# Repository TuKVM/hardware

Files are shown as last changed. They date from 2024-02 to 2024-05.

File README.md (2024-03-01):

# TuKVM Hardware

TuKVM is a hardware project that aims to provide a simple but feature rich IP KVM solution. The project is based on the [Tronlong SOM-TLT113](https://www.tronlong.com/Product/show/237.html) SoM, which includes an Allwinner T113-i SoC, with dual-core Cortex-A7 CPU, 256MB DDR3 RAM, and 4GB eMMC.

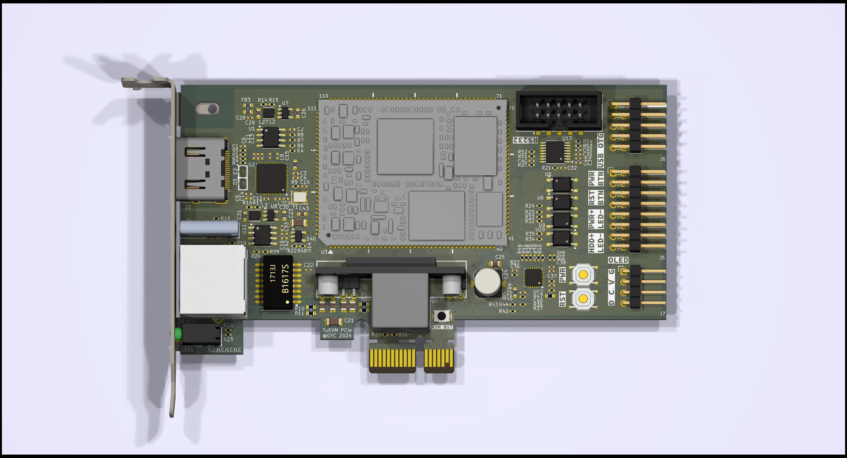
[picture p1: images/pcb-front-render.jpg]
PCB render image


## Features

* PCIe x1 half-height form factor, with breakable edge connector for mounting in systems without free slots
* HDMI input capture (up to 1080P30) with [MS2109](http://en.macrosilicon.com/info.asp?base_id=2&third_id=50) IC
* ATX power / reset button control with opto-isolator
* Power and HDD LED monitoring with opto-isolator
* 9 pin 2.54mm internal USB OTG port for mass-storage, keyboard, mouse emulation and Ethernet-over-USB
* USB-C external power input and UART console port for debugging
* 100Mbps Ethernet with [LAN8720A](https://www.microchip.com/en-us/product/lan8720a) PHY
* RS232 serial port with 2.54mm header for host system console redirection
* SMBus on PCIe connector for Linux kernel to recongnize the KVM as an IPMI device, using [ipmi_ssif](https://github.com/torvalds/linux/blob/master/drivers/char/ipmi/ipmi_ssif.c) driver
* (Optional) Isolated 802.3af PoE input with [DP1435-5V](https://item.szlcsc.com/6245786.html) controller module
* (Optional) I2C connector for an OLED status display module.

## Status

This project is currently in the prototyping phase. The hardware design is mostly complete, and the first prototype PCBs have been ordered. 

The firmware and software development isn't started yet, but the plan is to port [kvmd](https://github.com/pikvm/kvmd) from PiKVM project to the Allwinner T113-i SoC. Support for SMBus and IPMI protocol will need extra driver and software development. Any help is welcome!

## License

This project is licensed under the CERN Open Hardware License v2 - Permissive license. See the [LICENSE](LICENSE) file for details.

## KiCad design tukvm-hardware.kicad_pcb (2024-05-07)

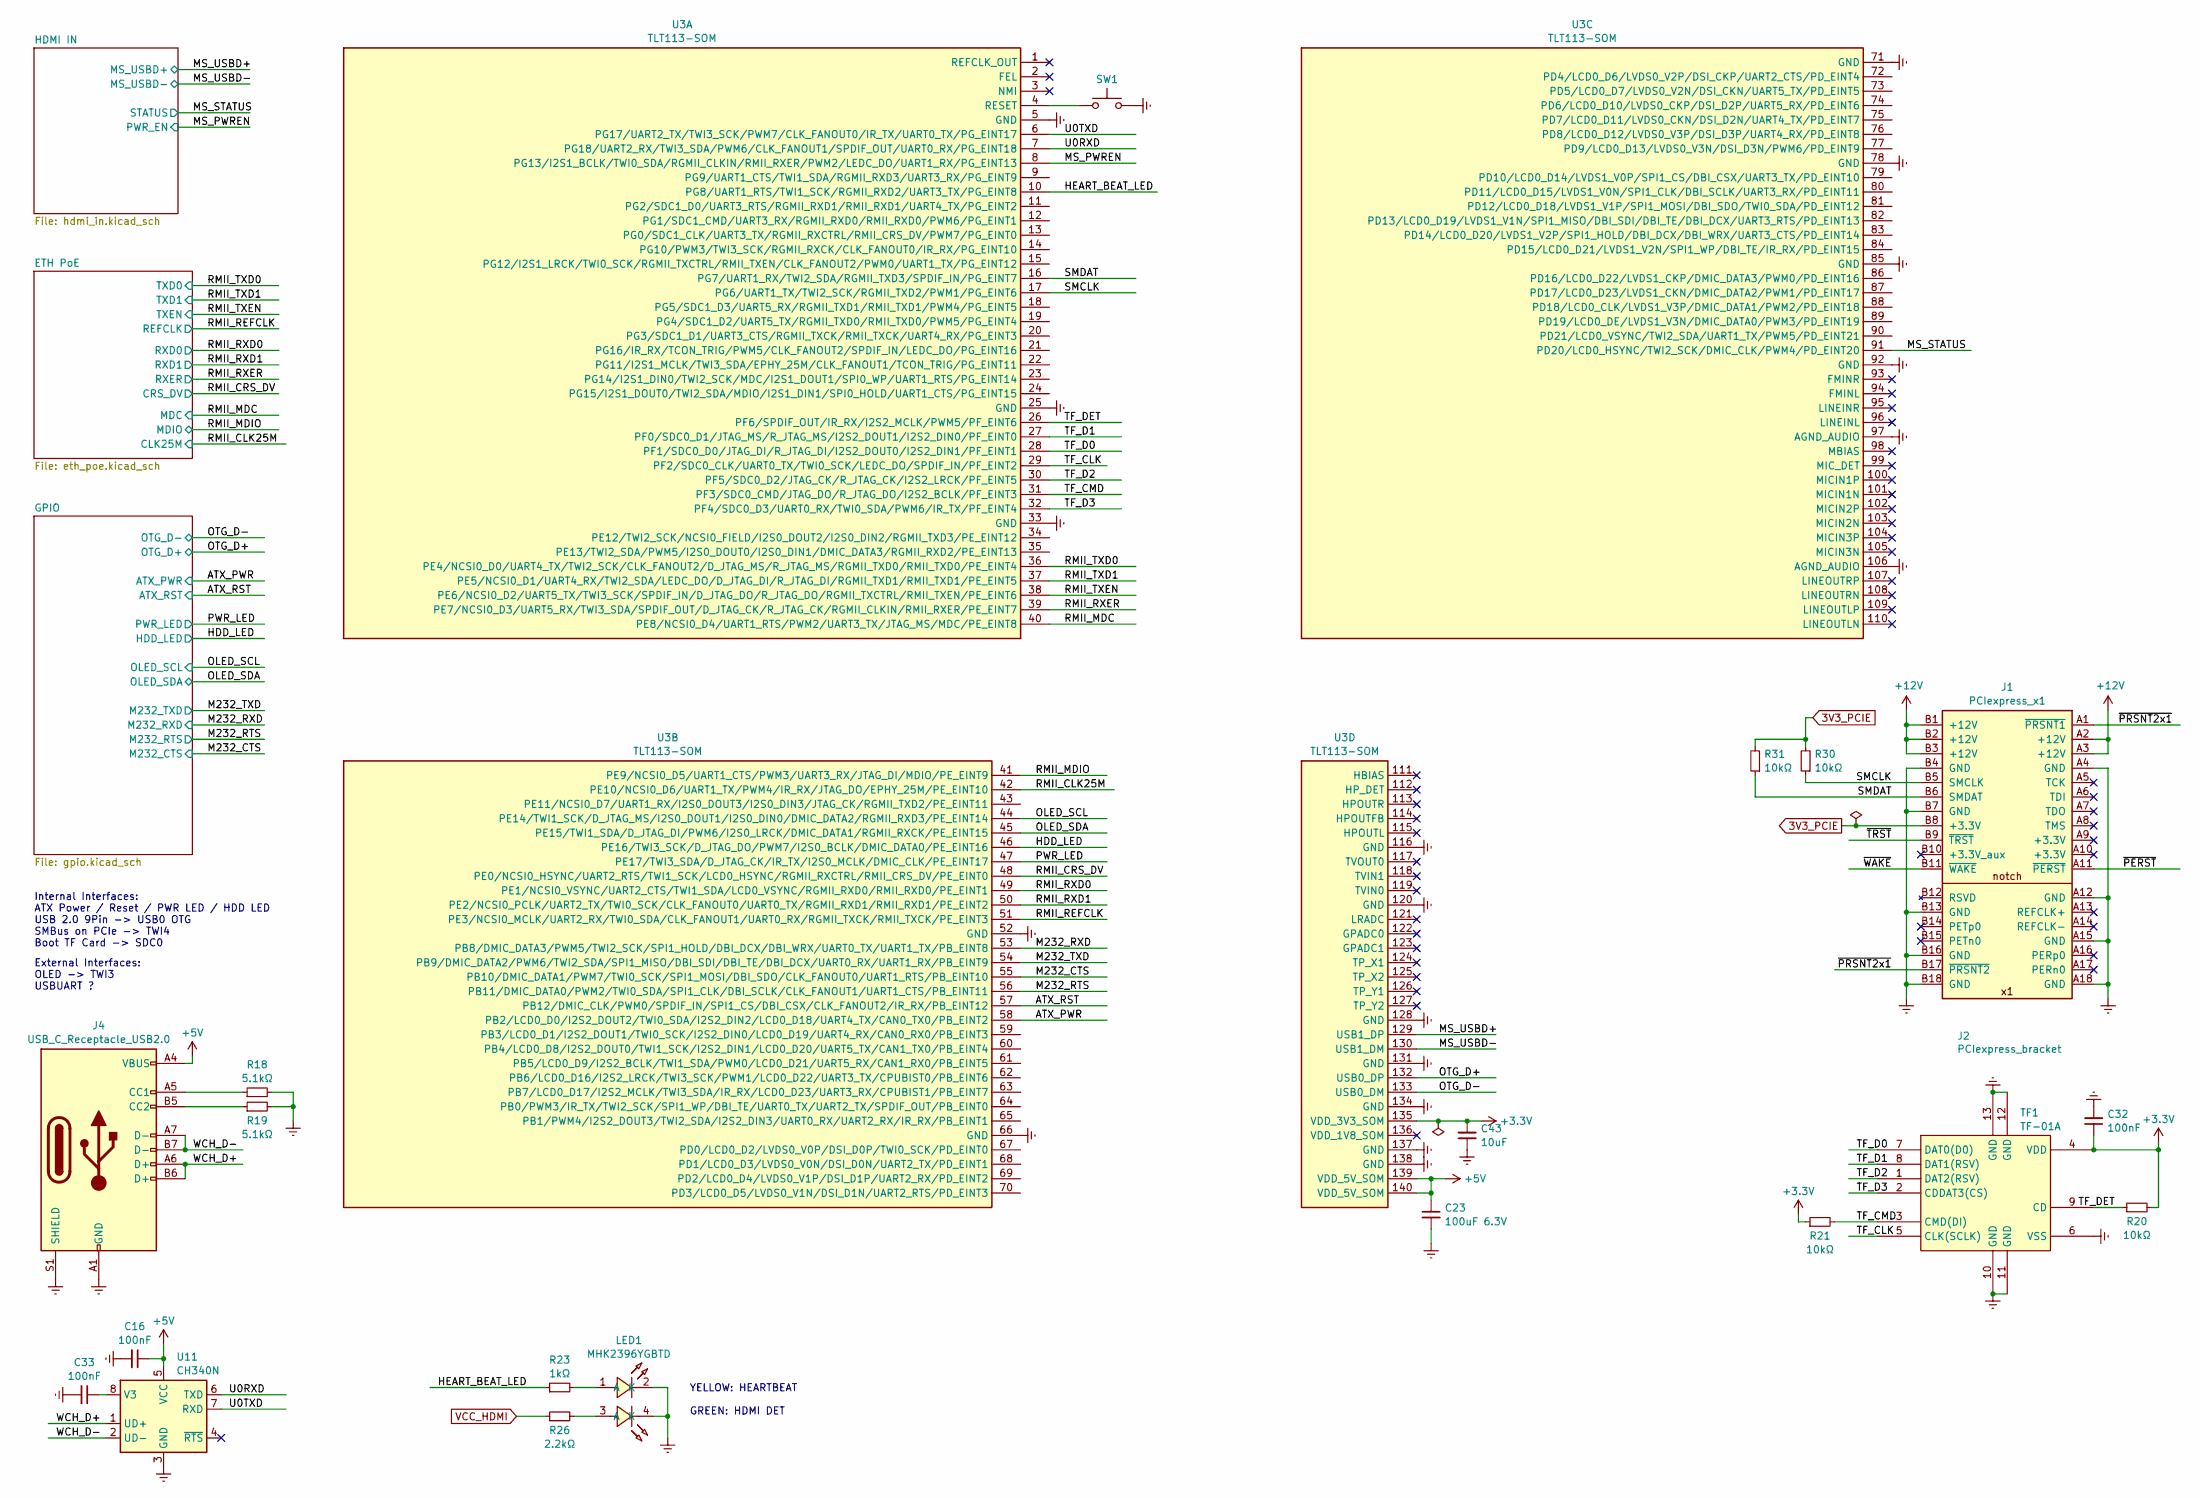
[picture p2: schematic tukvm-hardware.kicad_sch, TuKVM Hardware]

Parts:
C16, C32, C33: 100nF; C_0402_1005Metric
C23: 100uF 6.3V; C_1206_3216Metric
C43: 10uF; C_0603_1608Metric
J1: PCIexpress_x1
J2: PCIexpress_bracket; PCIexpress_bracket_low
J4: USB_C_Receptacle_USB2.0; USB-C-TH_TYPE-C-31-M-18
LED1: MHK2396YGBTD; LED-TH_MHK2396YGBTD; LCSC Part C2764899
R18, R19: 5.1kΩ; R_0402_1005Metric
R20, R21, R30, R31: 10kΩ; R_0402_1005Metric
R23: 1kΩ; R_0402_1005Metric
R26: 2.2kΩ; R_0402_1005Metric
SW1: SKRK; SW_Push_SPST_NO_Alps_SKRK
TF1: TF-01A; TF-SMD_TF-01A; LCSC Part C91145
U3: TLT113-SOM; SMD_140P_35X45_SOM_TLT113_PackageLength
U11: CH340N; SOP-8_3.9x4.9mm_P1.27mm

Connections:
3V3_PCIE: J1.B8 (+3.3V), R30.2, R31.2
+3.3V: C32.1, C43.2, R20.2, R21.1, TF1.4 (VDD), U3.135 (VDD_3V3_SOM); also elsewhere on the board
+5V: C16.1, C23.1, J4.A4 (VBUS), J4.A9 (VBUS), J4.B4 (VBUS), J4.B9 (VBUS), U3.139 (VDD_5V_SOM), U3.140 (VDD_5V_SOM), U11.5 (VCC); also elsewhere on the board
+12V: J1.A2 (+12V), J1.A3 (+12V), J1.B1 (+12V), J1.B2 (+12V), J1.B3 (+12V)
/ATX_PWR: U3.58 (PB2/LCD0_D0/I2S2_DOUT2/TWI0_SDA/I2S2_DI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); also elsewhere on the board
/ATX_RST: U3.57 (PB12/DMIC_CLK/PWM0/SPDIF_IN/SPI1_CS/DBI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); also elsewhere on the board
/HDD_LED: U3.46 (PE16/TWI3_SCK/D_JTAG_DO/PWM7/I2S0_BCLK/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); also elsewhere on the board
/HEART_BEAT_LED: R23.1, U3.10 (PG8/UART1_RTS/TWI1_SCK/RGMII_RXD2/UART3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)
/M232_CTS: U3.55 (PB10/DMIC_DATA1/PWM7/TWI0_SCK/SPI1_MOSI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); also elsewhere on the board
/M232_RTS: U3.56 (PB11/DMIC_DATA0/PWM2/TWI0_SDA/SPI1_CLK/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); also elsewhere on the board
/M232_RXD: U3.53 (PB8/DMIC_DATA3/PWM5/TWI2_SCK/SPI1_HOLD/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); also elsewhere on the board
/M232_TXD: U3.54 (PB9/DMIC_DATA2/PWM6/TWI2_SDA/SPI1_MISO/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); also elsewhere on the board
/MS_PWREN: U3.8 (PG13/I2S1_BCLK/TWI0_SDA/RGMII_CLKIN/RMI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); also elsewhere on the board
/MS_STATUS: U3.91 (PD20/LCD0_HSYNC/TWI2_SCK/DMIC_CLK/PWM4/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); also elsewhere on the board
/MS_USBD+: U3.129 (USB1_DP); also elsewhere on the board
/MS_USBD-: U3.130 (USB1_DM); also elsewhere on the board
/OLED_SCL: U3.44 (PE14/TWI1_SCK/D_JTAG_MS/I2S0_DOUT1/I2S0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); also elsewhere on the board
/OLED_SDA: U3.45 (PE15/TWI1_SDA/D_JTAG_DI/PWM6/I2S0_LRCK/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); also elsewhere on the board
/OTG_D+: U3.132 (USB0_DP); also elsewhere on the board
/OTG_D-: U3.133 (USB0_DM); also elsewhere on the board
/PWR_LED: U3.47 (PE17/TWI3_SDA/D_JTAG_CK/IR_TX/I2S0_MCLK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); also elsewhere on the board
/RMII_CLK25M: U3.42 (PE10/NCSI0_D6/UART1_TX/PWM4/IR_RX/JTAG_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); also elsewhere on the board
/RMII_CRS_DV: U3.48 (PE0/NCSI0_HSYNC/UART2_RTS/TWI1_SCK/LCD0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); also elsewhere on the board
/RMII_MDC: U3.40 (PE8/NCSI0_D4/UART1_RTS/PWM2/UART3_TX/JT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); also elsewhere on the board
/RMII_MDIO: U3.41 (PE9/NCSI0_D5/UART1_CTS/PWM3/UART3_RX/JT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); also elsewhere on the board
/RMII_REFCLK: U3.51 (PE3/NCSI0_MCLK/UART2_RX/TWI0_SDA/CLK_FA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); also elsewhere on the board
/RMII_RXD0: U3.49 (PE1/NCSI0_VSYNC/UART2_CTS/TWI1_SDA/LCD0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); also elsewhere on the board
/RMII_RXD1: U3.50 (PE2/NCSI0_PCLK/UART2_TX/TWI0_SCK/CLK_FA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); also elsewhere on the board
/RMII_RXER: U3.39 (PE7/NCSI0_D3/UART5_RX/TWI3_SDA/SPDIF_OU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); also elsewhere on the board
/RMII_TXD0: U3.36 (PE4/NCSI0_D0/UART4_TX/TWI2_SCK/CLK_FANO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); also elsewhere on the board
/RMII_TXD1: U3.37 (PE5/NCSI0_D1/UART4_RX/TWI2_SDA/LEDC_DO/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); also elsewhere on the board
/RMII_TXEN: U3.38 (PE6/NCSI0_D2/UART5_TX/TWI3_SCK/SPDIF_IN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); also elsewhere on the board
/SMCLK: J1.B5 (SMCLK), R30.1, U3.17 (PG6/UART1_TX/TWI2_SCK/RGMII_TXD2/PWM1/P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)
/SMDAT: J1.B6 (SMDAT), R31.1, U3.16 (PG7/UART1_RX/TWI2_SDA/RGMII_TXD3/SPDIF_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)
/TF_CLK: TF1.5 (CLK(SCLK)), U3.29 (PF2/SDC0_CLK/UART0_TX/TWI0_SCK/LEDC_DO/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)
/TF_CMD: R21.2, TF1.3 (CMD(DI)), U3.31 (PF3/SDC0_CMD/JTAG_DO/R_JTAG_DO/I2S2_BCL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)
/TF_D0: TF1.7 (DAT0(D0)), U3.28 (PF1/SDC0_D0/JTAG_DI/R_JTAG_DI/I2S2_DOUT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)
/TF_D1: TF1.8 (DAT1(RSV)), U3.27 (PF0/SDC0_D1/JTAG_MS/R_JTAG_MS/I2S2_DOUT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)
/TF_D2: TF1.1 (DAT2(RSV)), U3.30 (PF5/SDC0_D2/JTAG_CK/R_JTAG_CK/I2S2_LRCK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)
/TF_D3: TF1.2 (CDDAT3(CS)), U3.32 (PF4/SDC0_D3/UART0_RX/TWI0_SDA/PWM6/IR_T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)
/TF_DET: R20.1, TF1.9 (CD), U3.26 (PF6/SPDIF_OUT/IR_RX/I2S2_MCLK/PWM5/PF_E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)
/U0RXD: U3.7 (PG18/UART2_RX/TWI3_SDA/PWM6/CLK_FANOUT1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), U11.6 (TXD)
/U0TXD: U3.6 (PG17/UART2_TX/TWI3_SCK/PWM7/CLK_FANOUT0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), U11.7 (RXD)
/WCH_D+: J4.A6 (D+), J4.B6 (D+), U11.1 (UD+)
/WCH_D-: J4.A7 (D-), J4.B7 (D-), U11.2 (UD-)
/~PERST: J1.A11 (~PERST)
/~PRSNT2x1: J1.A1 (~PRSNT1), J1.B17 (~PRSNT2)
/~TRST: J1.B9 (~TRST)
/~WAKE: J1.B11 (~WAKE)
Earth: C16.2, C23.2, C32.2, C33.2, C43.1, J1.A4 (GND), J1.A12 (GND), J1.A15 (GND), J1.A18 (GND), J1.B4 (GND), J1.B7 (GND), J1.B13 (GND), J1.B16 (GND), J1.B18 (GND), J4.A1 (GND), J4.A12 (GND), J4.B1 (GND), J4.B12 (GND), J4.S1 (SHIELD), LED1.2 (K), LED1.4 (K), R18.2, R19.2, SW1.2, TF1.6 (VSS), TF1.10 (GND), TF1.11 (GND), TF1.12 (GND), TF1.13 (GND), U3.5 (GND), U3.25 (GND), U3.33 (GND), U3.52 (GND), U3.66 (GND), U3.71 (GND), U3.78 (GND), U3.85 (GND), U3.92 (GND), U3.97 (AGND_AUDIO), U3.106 (AGND_AUDIO), U3.116 (GND), U3.120 (GND), U3.128 (GND), U3.131 (GND), U3.134 (GND), U3.137 (GND), U3.138 (GND), U11.3 (GND); also elsewhere on the board
unnamed: J4.A5 (CC1), R18.1
unnamed: J4.B5 (CC2), R19.1
unnamed: LED1.1 (A), R23.2
unnamed: LED1.3 (A), R26.2
unnamed: SW1.1, U3.4 (RESET)
unnamed: C33.1, U11.8 (V3)
VCC_HDMI: R26.1; also elsewhere on the board

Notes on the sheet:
External Interfaces: OLED -> TWI3 USBUART ?
YELLOW: HEARTBEAT GREEN: HDMI DET
Internal Interfaces: ATX Power / Reset / PWR LED / HDD LED USB 2.0 9Pin -> USB0 OTG SMBus on PCIe -> TWI4 Boot TF Card -> SDC0

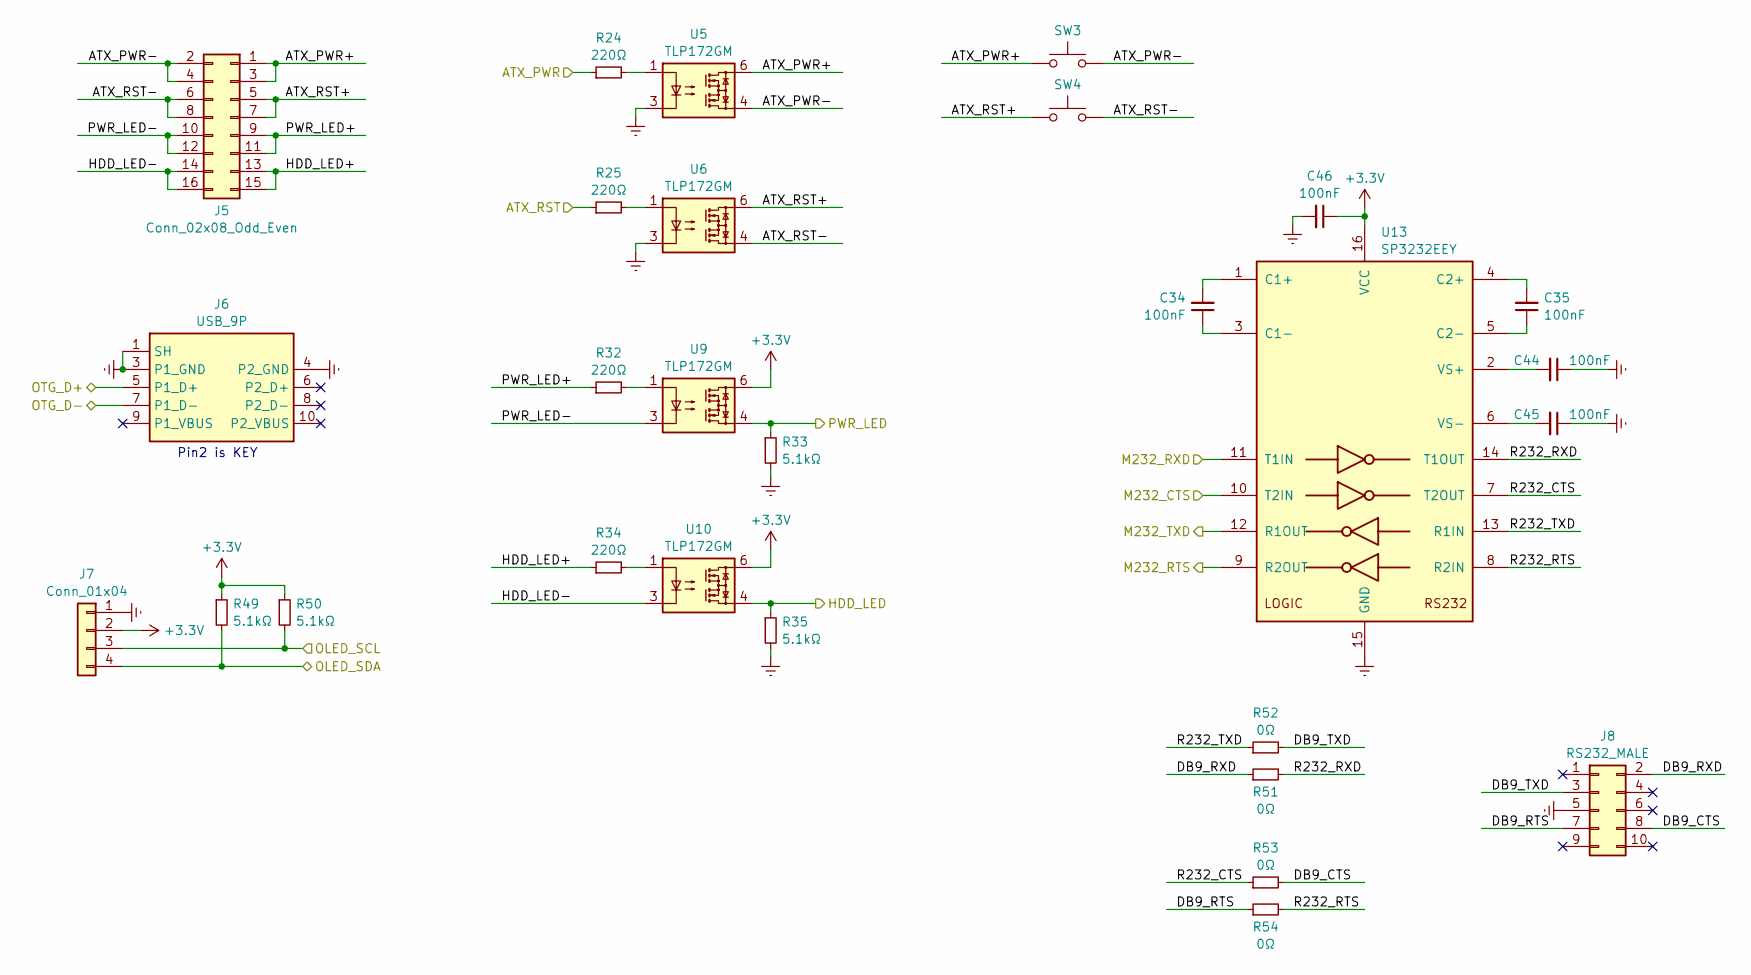
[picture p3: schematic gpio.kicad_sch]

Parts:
C34, C35, C44, C45, C46: 100nF; C_0402_1005Metric
J5: Conn_02x08_Odd_Even; PinHeader_2x08_P2.54mm_Horizontal
J6: USB_9P; USB_9P_P2.54mm_Horizontal
J7: Conn_01x04; PinHeader_1x04_P2.54mm_Horizontal
J8: RS232_MALE; IDC-SMD_10P-P2.54-V-R2-C5-S9.50
R24, R25, R32, R34: 220Ω; R_0402_1005Metric
R33, R35, R49, R50: 5.1kΩ; R_0402_1005Metric
R51, R52, R53, R54: 0Ω; R_0402_1005Metric
SW3, SW4: TS-1187A; SW_Push_1P1T_XKB_TS-1187A
U5, U6, U9, U10: TLP172GM; MFSOP6-4_4.4x3.6mm_P1.27mm; LCSC Part C261926
U13: SP3232EEY; TSSOP-16_4.4x5mm_P0.65mm; LCSC Part C13482

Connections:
+3.3V: C46.1, J7.2, R49.1, R50.1, U9.6, U10.6, U13.16 (VCC); also elsewhere on the board
/ATX_PWR: R24.1; also elsewhere on the board
/ATX_RST: R25.1; also elsewhere on the board
/GPIO/ATX_PWR+: J5.1, J5.3, SW3.1, U5.6
/GPIO/ATX_PWR-: J5.2, J5.4, SW3.2, U5.4
/GPIO/ATX_RST+: J5.5, J5.7, SW4.1, U6.6
/GPIO/ATX_RST-: J5.6, J5.8, SW4.2, U6.4
/GPIO/DB9_CTS: J8.8, R53.2
/GPIO/DB9_RTS: J8.7, R54.1
/GPIO/DB9_RXD: J8.2, R51.1
/GPIO/DB9_TXD: J8.3, R52.2
/GPIO/HDD_LED+: J5.13, J5.15, R34.1
/GPIO/HDD_LED-: J5.14, J5.16, U10.3
/GPIO/PWR_LED+: J5.9, J5.11, R32.1
/GPIO/PWR_LED-: J5.10, J5.12, U9.3
/GPIO/R232_CTS: R53.1, U13.7 (T2OUT)
/GPIO/R232_RTS: R54.2, U13.8 (R2IN)
/GPIO/R232_RXD: R51.2, U13.14 (T1OUT)
/GPIO/R232_TXD: R52.1, U13.13 (R1IN)
/HDD_LED: R35.1, U10.4; also elsewhere on the board
/M232_CTS: U13.10 (T2IN); also elsewhere on the board
/M232_RTS: U13.9 (R2OUT); also elsewhere on the board
/M232_RXD: U13.11 (T1IN); also elsewhere on the board
/M232_TXD: U13.12 (R1OUT); also elsewhere on the board
/OLED_SCL: J7.3, R50.2; also elsewhere on the board
/OLED_SDA: J7.4, R49.2; also elsewhere on the board
/OTG_D+: J6.5 (P1_D+); also elsewhere on the board
/OTG_D-: J6.7 (P1_D-); also elsewhere on the board
/PWR_LED: R33.1, U9.4; also elsewhere on the board
Earth: C44.1, C45.1, C46.2, J6.1 (SH), J6.3 (P1_GND), J6.4 (P2_GND), J7.1, J8.5, R33.2, R35.2, U5.3, U6.3, U13.15 (GND); also elsewhere on the board
unnamed: R24.2, U5.1
unnamed: R25.2, U6.1
unnamed: R32.2, U9.1
unnamed: R34.2, U10.1
unnamed: C34.2, U13.1 (C1+)
unnamed: C34.1, U13.3 (C1-)
unnamed: C35.2, U13.4 (C2+)
unnamed: C35.1, U13.5 (C2-)
unnamed: C44.2, U13.2 (VS+)
unnamed: C45.2, U13.6 (VS-)

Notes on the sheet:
Pin2 is KEY

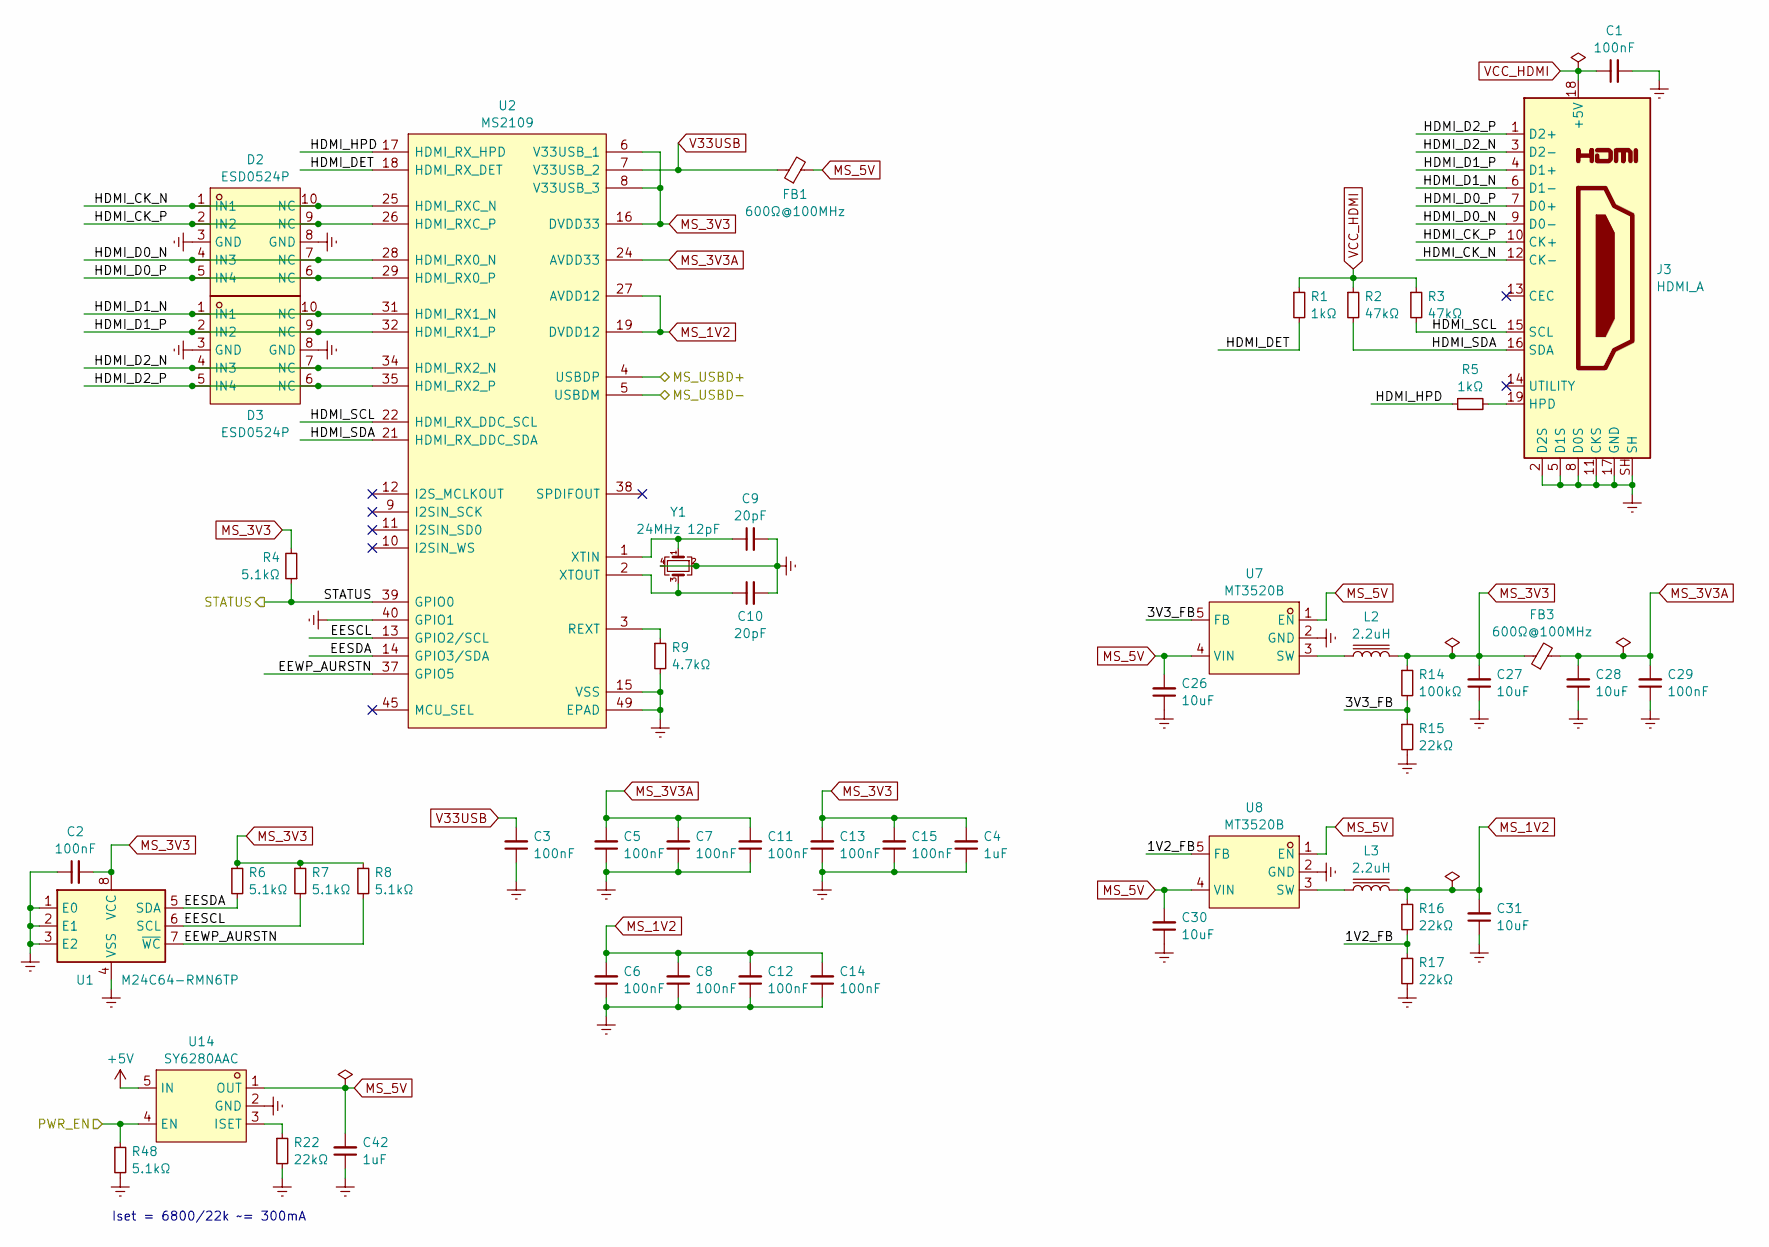
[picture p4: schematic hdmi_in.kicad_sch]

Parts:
C1, C2, C3, C5, C6, C7, C8, C11, C12, C13, C14, C15, C29: 100nF; C_0402_1005Metric
C4, C42: 1uF; C_0402_1005Metric
C9, C10: 20pF; C_0402_1005Metric
C26, C27, C28, C30, C31: 10uF; C_0603_1608Metric
D2, D3: ESD0524P; DFN-10_L2.5-W1.0-P0.50-BL; LCSC Part C484320
FB1, FB3: 600Ω@100MHz; L_0603_1608Metric; LCSC Part C1002
J3: HDMI_A; HDMI_A_Molex_208658-1001_Horizontal
L2, L3: 2.2uH; L_Cenker_CKCS201610; LCSC Part C354533
R1, R5: 1kΩ; R_0402_1005Metric
R2, R3: 47kΩ; R_0402_1005Metric
R4, R6, R7, R8, R48: 5.1kΩ; R_0402_1005Metric
R9: 4.7kΩ; R_0402_1005Metric
R14: 100kΩ; R_0402_1005Metric
R15, R16, R17, R22: 22kΩ; R_0402_1005Metric
U1: M24C64-RMN6TP; SOIC-8_3.9x4.9mm_P1.27mm; LCSC Part C79988
U2: MS2109; QFN-48-1EP_7x7mm_P0.5mm_EP5.1x5.1mm
U7, U8: MT3520B; SOT-23-5; LCSC Part C2684933
U14: SY6280AAC; SOT-23-5; LCSC Part C55136
Y1: 24MHz 12pF; Crystal_SMD_3225-4Pin_3.2x2.5mm; LCSC Part C271629

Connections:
+5V: U14.5 (IN); also elsewhere on the board
/HDMI IN/1V2_FB: R16.2, R17.1, U8.5 (FB)
/HDMI IN/3V3_FB: R14.2, R15.1, U7.5 (FB)
/HDMI IN/EESCL: R7.2, U1.6 (SCL), U2.13 (GPIO2/SCL)
/HDMI IN/EESDA: R6.2, U1.5 (SDA), U2.14 (GPIO3/SDA)
/HDMI IN/EEWP_AURSTN: R8.2, U1.7 (~WC), U2.37 (GPIO5)
/HDMI IN/HDMI_CK_N: D2.1 (IN1), D2.10 (NC), J3.12 (CK-), U2.25 (HDMI_RXC_N)
/HDMI IN/HDMI_CK_P: D2.2 (IN2), D2.9 (NC), J3.10 (CK+), U2.26 (HDMI_RXC_P)
/HDMI IN/HDMI_D0_N: D2.4 (IN3), D2.7 (NC), J3.9 (D0-), U2.28 (HDMI_RX0_N)
/HDMI IN/HDMI_D0_P: D2.5 (IN4), D2.6 (NC), J3.7 (D0+), U2.29 (HDMI_RX0_P)
/HDMI IN/HDMI_D1_N: D3.1 (IN1), D3.10 (NC), J3.6 (D1-), U2.31 (HDMI_RX1_N)
/HDMI IN/HDMI_D1_P: D3.2 (IN2), D3.9 (NC), J3.4 (D1+), U2.32 (HDMI_RX1_P)
/HDMI IN/HDMI_D2_N: D3.4 (IN3), D3.7 (NC), J3.3 (D2-), U2.34 (HDMI_RX2_N)
/HDMI IN/HDMI_D2_P: D3.5 (IN4), D3.6 (NC), J3.1 (D2+), U2.35 (HDMI_RX2_P)
/HDMI IN/HDMI_DET: R1.2, U2.18 (HDMI_RX_DET)
/HDMI IN/HDMI_HPD: R5.1, U2.17 (HDMI_RX_HPD)
/HDMI IN/HDMI_SCL: J3.15 (SCL), R3.2, U2.22 (HDMI_RX_DDC_SCL)
/HDMI IN/HDMI_SDA: J3.16 (SDA), R2.2, U2.21 (HDMI_RX_DDC_SDA)
/MS_PWREN: R48.1, U14.4 (EN); also elsewhere on the board
/MS_STATUS: R4.1, U2.39 (GPIO0); also elsewhere on the board
/MS_USBD+: U2.4 (USBDP); also elsewhere on the board
/MS_USBD-: U2.5 (USBDM); also elsewhere on the board
Earth: C1.2, C2.1, C3.1, C4.1, C5.1, C6.1, C7.1, C8.1, C9.2, C10.2, C11.1, C12.1, C13.1, C14.1, C15.1, C26.1, C27.1, C28.1, C29.1, C30.1, C31.1, C42.1, D2.3 (GND), D2.8 (GND), D3.3 (GND), D3.8 (GND), J3.2 (D2S), J3.5 (D1S), J3.8 (D0S), J3.11 (CKS), J3.17 (GND), J3.SH, R9.2, R15.2, R17.2, R22.2, R48.2, U1.1 (E0), U1.2 (E1), U1.3 (E2), U1.4 (VSS), U2.15 (VSS), U2.20 (VSS), U2.36 (VSS), U2.40 (GPIO1), U2.42 (VSS), U2.43 (VSS), U2.46 (VSS), U2.48 (VSS), U2.49 (EPAD), U7.2 (GND), U8.2 (GND), U14.2 (GND), Y1.2, Y1.4; also elsewhere on the board
MS_1V2: C6.2, C8.2, C12.2, C14.2, C31.2, L3.2, R16.1, U2.19 (DVDD12), U2.27 (AVDD12), U2.33 (AVDD12), U2.41 (DVDD12)
MS_3V3: C2.2, C4.2, C13.2, C15.2, C27.2, FB3.1, L2.2, R4.2, R6.1, R7.1, R8.1, R14.1, U1.8 (VCC), U2.6 (V33USB_1), U2.8 (V33USB_3), U2.16 (DVDD33), U2.23 (DVDD33), U2.44 (DVDD33)
MS_3V3A: C5.2, C7.2, C11.2, C28.2, C29.2, FB3.2, U2.24 (AVDD33), U2.30 (AVDD33), U2.47 (AVDD33)
MS_5V: C26.2, C30.2, C42.2, FB1.2, U7.1 (EN), U7.4 (VIN), U8.1 (EN), U8.4 (VIN), U14.1 (OUT)
unnamed: J3.19 (HPD), R5.2
unnamed: R9.1, U2.3 (REXT)
unnamed: C9.1, U2.1 (XTIN), Y1.1
unnamed: C10.1, U2.2 (XTOUT), Y1.3
unnamed: L2.1, U7.3 (SW)
unnamed: L3.1, U8.3 (SW)
unnamed: R22.1, U14.3 (ISET)
V33USB: C3.2, FB1.1, U2.7 (V33USB_2)
VCC_HDMI: C1.1, J3.18 (+5V), R1.1, R2.1, R3.1; also elsewhere on the board

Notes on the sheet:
Iset = 6800/22k ~= 300mA

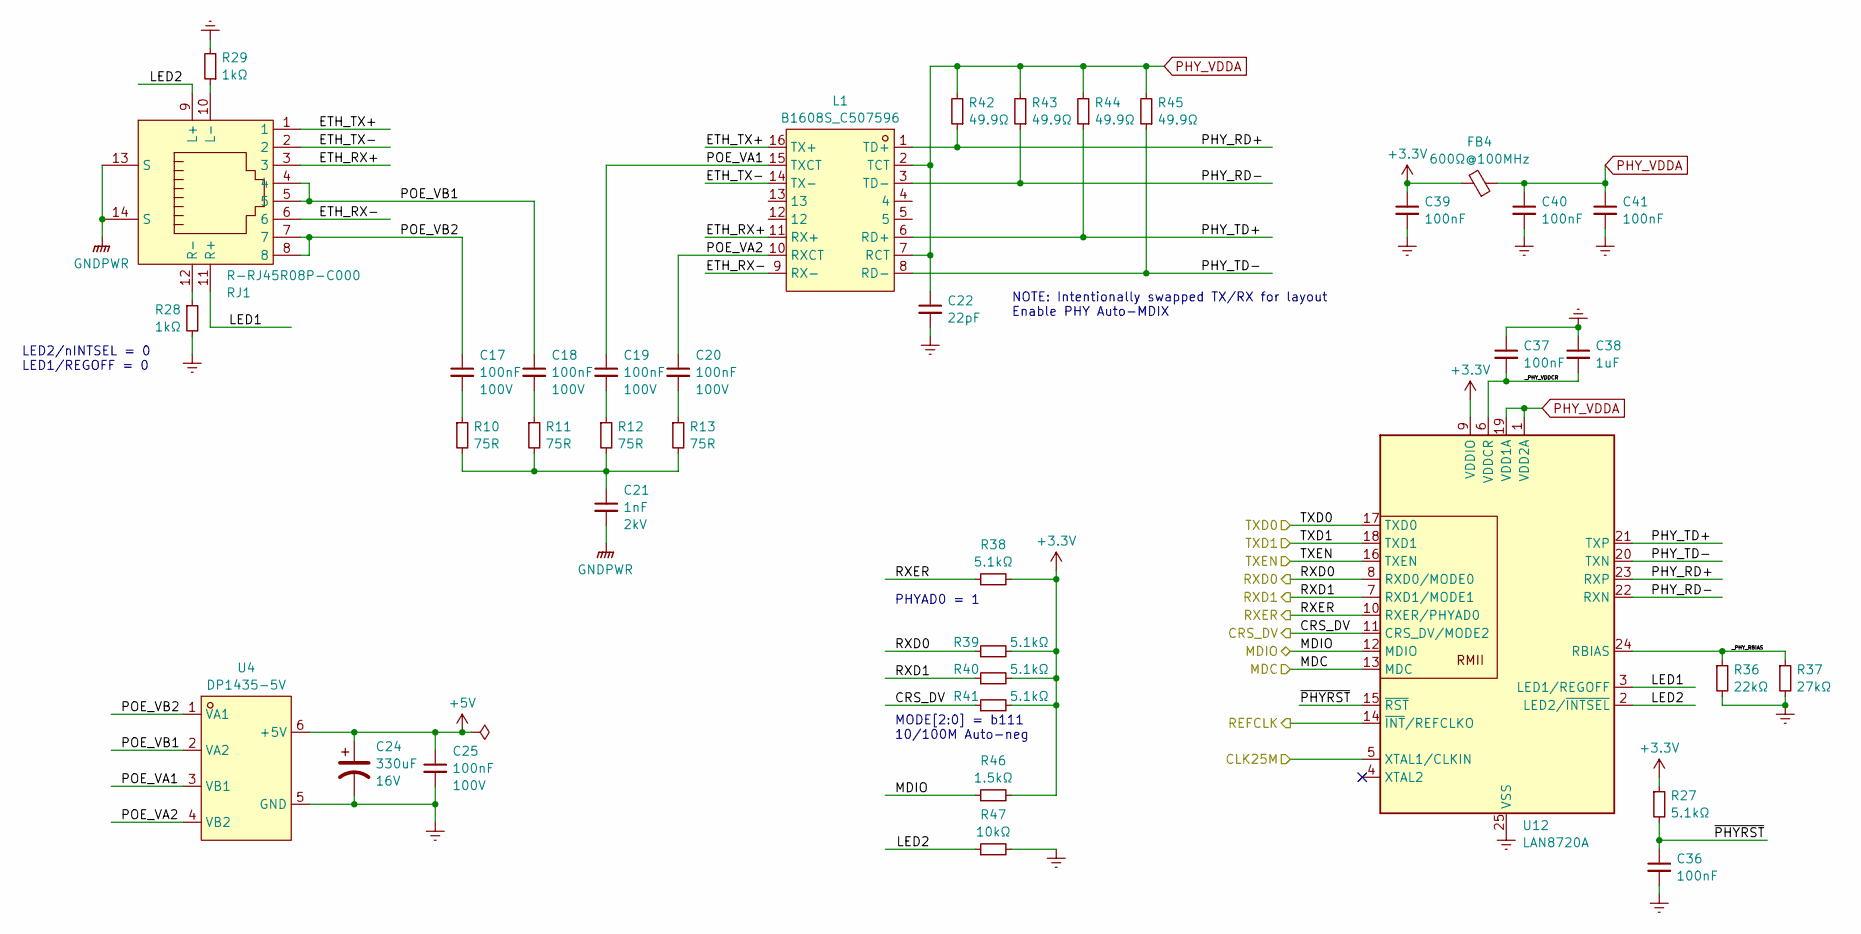
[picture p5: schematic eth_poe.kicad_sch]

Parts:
C17, C18, C19, C20, C25: 100nF; C_0805_2012Metric; Voltage 100V
C21: 1nF; C_1206_3216Metric; Voltage 2kV
C22: 22pF; C_0402_1005Metric
C24: 330uF; C_Elec_6.3x7.7; Voltage 16V
C36, C37, C39, C40, C41: 100nF; C_0402_1005Metric
C38: 1uF; C_0402_1005Metric
FB4: 600Ω@100MHz; L_0603_1608Metric; LCSC Part C1002
L1: B1608S_C507596; SMD-16_L12.7-W7.0-P1.27-LS9.5-BL; LCSC Part C507596
R10, R11, R12, R13: 75R; R_0603_1608Metric
R27, R38, R39, R40, R41: 5.1kΩ; R_0402_1005Metric
R28, R29: 1kΩ; R_0402_1005Metric
R36: 22kΩ; R_0402_1005Metric
R37: 27kΩ; R_0603_1608Metric
R42, R43, R44, R45: 49.9Ω; R_0402_1005Metric
R46: 1.5kΩ; R_0402_1005Metric
R47: 10kΩ; R_0402_1005Metric
RJ1: R-RJ45R08P-C000; RJ45-TH_R-RJ45R08P-C000; LCSC Part C386757
U4: DP1435-5V; PWRM-TH_DP1435-XX; LCSC Part C5380097
U12: LAN8720A; VQFN-24-1EP_4x4mm_P0.5mm_EP2.5x2.5mm

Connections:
+3.3V: C39.1, FB4.2, R27.1, R38.2, R39.2, R40.2, R41.2, R46.2, U12.9 (VDDIO); also elsewhere on the board
+5V: C24.1, C25.1, U4.6 (+5V); also elsewhere on the board
/ETH PoE/ETH_RX+: L1.11 (RX+), RJ1.3
/ETH PoE/ETH_RX-: L1.9 (RX-), RJ1.6
/ETH PoE/ETH_TX+: L1.16 (TX+), RJ1.1
/ETH PoE/ETH_TX-: L1.14 (TX-), RJ1.2
/ETH PoE/LED1: RJ1.11 (R+), U12.3 (LED1/REGOFF)
/ETH PoE/LED2: R47.1, RJ1.9 (L+), U12.2 (LED2/~INTSEL)
/ETH PoE/PHY_RD+: L1.1 (TD+), R42.1, U12.23 (RXP)
/ETH PoE/PHY_RD-: L1.3 (TD-), R43.1, U12.22 (RXN)
/ETH PoE/PHY_TD+: L1.6 (RD+), R44.1, U12.21 (TXP)
/ETH PoE/PHY_TD-: L1.8 (RD-), R45.1, U12.20 (TXN)
/ETH PoE/POE_VA1: C19.1, L1.15 (TXCT), U4.3 (VB1)
/ETH PoE/POE_VA2: C20.1, L1.10 (RXCT), U4.4 (VB2)
/ETH PoE/POE_VB1: C18.1, RJ1.4, RJ1.5, U4.2 (VA2)
/ETH PoE/POE_VB2: C17.1, RJ1.7, RJ1.8, U4.1 (VA1)
/ETH PoE/_PHY_RBIAS: R36.1, R37.1, U12.24 (RBIAS)
/ETH PoE/_PHY_VDDCR: C37.2, C38.2, U12.6 (VDDCR)
/ETH PoE/~PHYRST: C36.1, R27.2, U12.15 (~RST)
/RMII_CLK25M: U12.5 (XTAL1/CLKIN); also elsewhere on the board
/RMII_CRS_DV: R41.1, U12.11 (CRS_DV/MODE2); also elsewhere on the board
/RMII_MDC: U12.13 (MDC); also elsewhere on the board
/RMII_MDIO: R46.1, U12.12 (MDIO); also elsewhere on the board
/RMII_REFCLK: U12.14 (~INT/REFCLKO); also elsewhere on the board
/RMII_RXD0: R39.1, U12.8 (RXD0/MODE0); also elsewhere on the board
/RMII_RXD1: R40.1, U12.7 (RXD1/MODE1); also elsewhere on the board
/RMII_RXER: R38.1, U12.10 (RXER/PHYAD0); also elsewhere on the board
/RMII_TXD0: U12.17 (TXD0); also elsewhere on the board
/RMII_TXD1: U12.18 (TXD1); also elsewhere on the board
/RMII_TXEN: U12.16 (TXEN); also elsewhere on the board
Earth: C22.2, C24.2, C25.2, C36.2, C37.1, C38.1, C39.2, C40.2, C41.2, R28.2, R29.2, R36.2, R37.2, R47.2, U4.5 (GND), U12.25 (VSS); also elsewhere on the board
GNDPWR: C21.2, RJ1.13 (S), RJ1.14 (S)
unnamed: C17.2, R10.1
unnamed: C18.2, R11.1
unnamed: C19.2, R12.1
unnamed: C20.2, R13.1
unnamed: C21.1, R10.2, R11.2, R12.2, R13.2
unnamed: R29.1, RJ1.10 (L-)
unnamed: R28.1, RJ1.12 (R-)
PHY_VDDA: C22.1, C40.1, C41.1, FB4.1, L1.2 (TCT), L1.7 (RCT), R42.2, R43.2, R44.2, R45.2, U12.1 (VDD2A), U12.19 (VDD1A)

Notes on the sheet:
LED2/nINTSEL = 0 LED1/REGOFF = 0
PHYAD0 = 1
NOTE: Intentionally swapped TX/RX for layout Enable PHY Auto-MDIX
MODE[2:0] = b111 10/100M Auto-neg

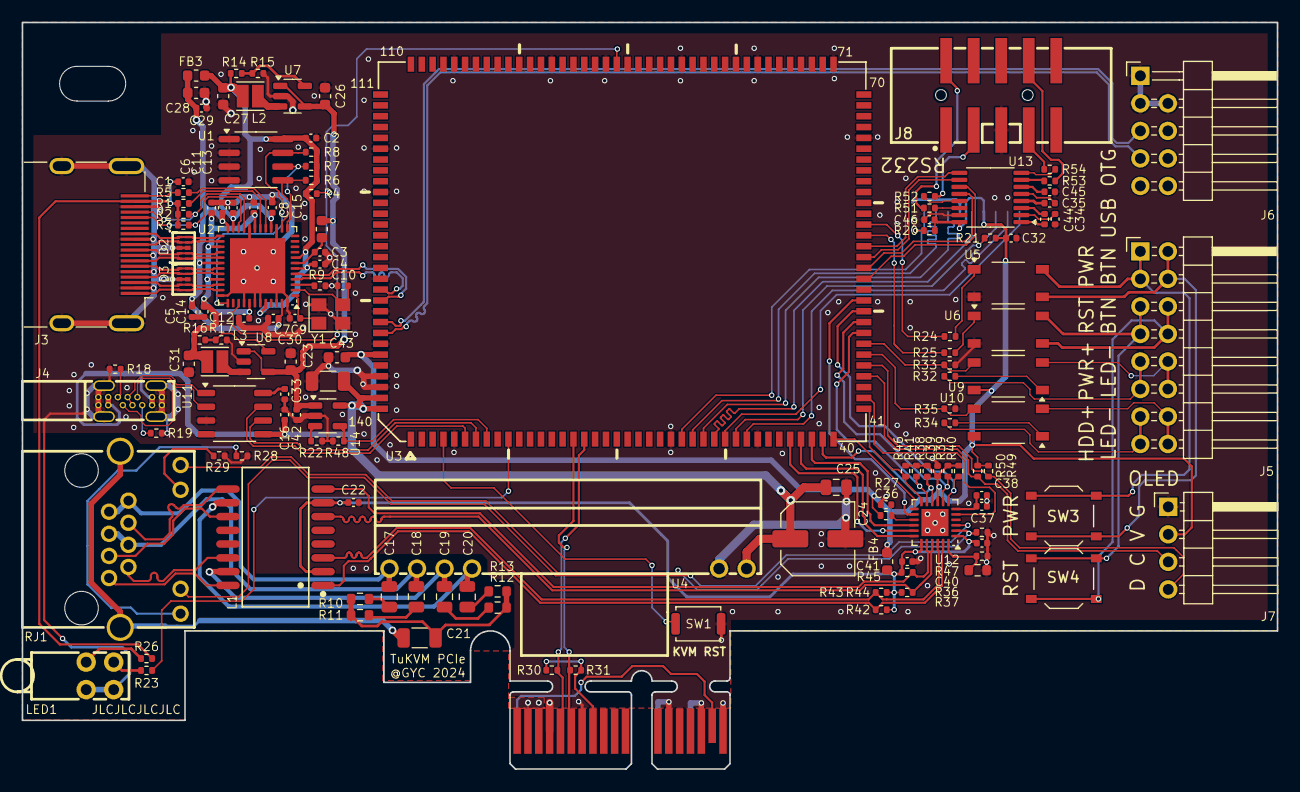
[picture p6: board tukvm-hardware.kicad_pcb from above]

Board: 2 copper layers, 115.8 x 68.9 mm, 137 parts (1 on the bottom side), 135 nets.

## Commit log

2024-02-25 Add sch & pcb for MCORE-H616 version
    [eth_poe.kicad_sch, gpio.kicad_sch, hdmi_in.kicad_sch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]
2024-02-29 Update pcb & sch for T113 SOM
    [eth_poe.kicad_sch, gpio.kicad_sch, hdmi_in.kicad_sch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]
2024-02-29 Add 3dmodels for some parts
    [tukvm-hardware.kicad_pcb]
2024-03-10 Fix MS2109 symbol power pins, initial v1 release
    [gpio.kicad_sch, hdmi_in.kicad_sch, tukvm-hardware.kicad_pcb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]
2024-05-07 Fix OTG USB polarity
    [eth_poe.kicad_sch, gpio.kicad_sch, hdmi_in.kicad_sch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]
